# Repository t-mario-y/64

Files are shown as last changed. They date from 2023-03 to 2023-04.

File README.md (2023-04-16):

# 64

Splitted, Cherry MX switch, 64 keys, ortholinear mechanical keyboard.

MCU: [Waveshare RP2040-zero](https://www.waveshare.com/wiki/RP2040-Zero)  
Firmware: [KMK firmware](https://github.com/KMKfw/kmk_firmware)  

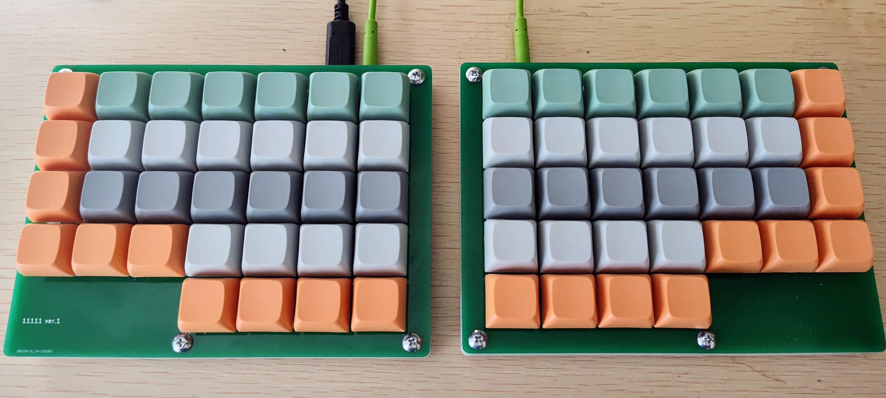
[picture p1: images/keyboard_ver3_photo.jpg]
keyboard photo. this is actually ver3 but top plates reuses ver1.


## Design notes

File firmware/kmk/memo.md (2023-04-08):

# Using KMK firmware

current working version:

- [Waveshare RP2040-zero](https://www.waveshare.com/wiki/RP2040-Zero)
- [CircuitPython 8.0.5](https://circuitpython.org/board/waveshare_rp2040_zero/)
- [KMK firmware b84cd0bdab5fce47534df7e6ccfbadb2e3288ba5](https://github.com/KMKfw/kmk_firmware/commit/b84cd0bdab5fce47534df7e6ccfbadb2e3288ba5)

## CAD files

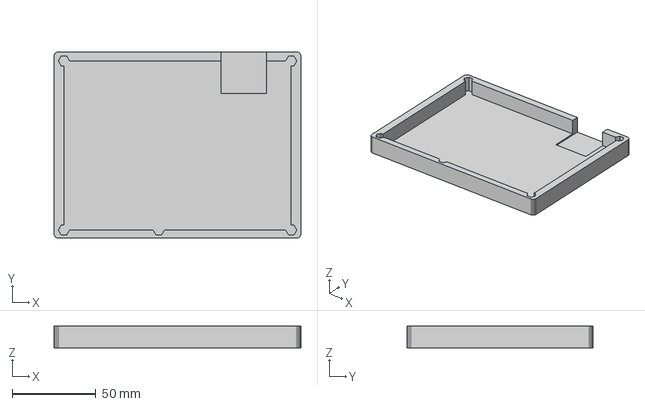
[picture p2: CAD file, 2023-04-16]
dist/ver3/models/left-case.step
147.4 x 111.1 x 13.0 mm

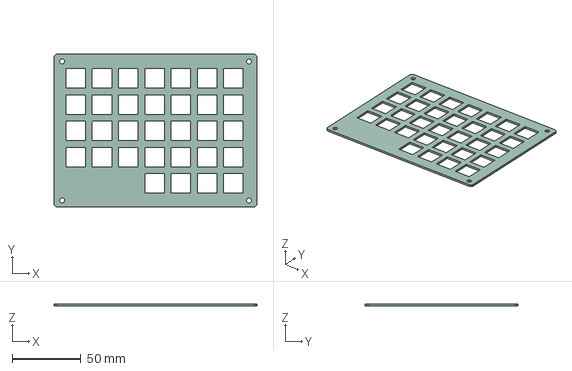
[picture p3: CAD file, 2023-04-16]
dist/ver3/models/top-plate.step
147.4 x 111.1 x 1.58 mm

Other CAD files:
dist/ver3/models/right-case.step
dist/ver3/models/left-case.stl
dist/ver3/models/right-case.stl
dist/ver3/models/top-plate.stl

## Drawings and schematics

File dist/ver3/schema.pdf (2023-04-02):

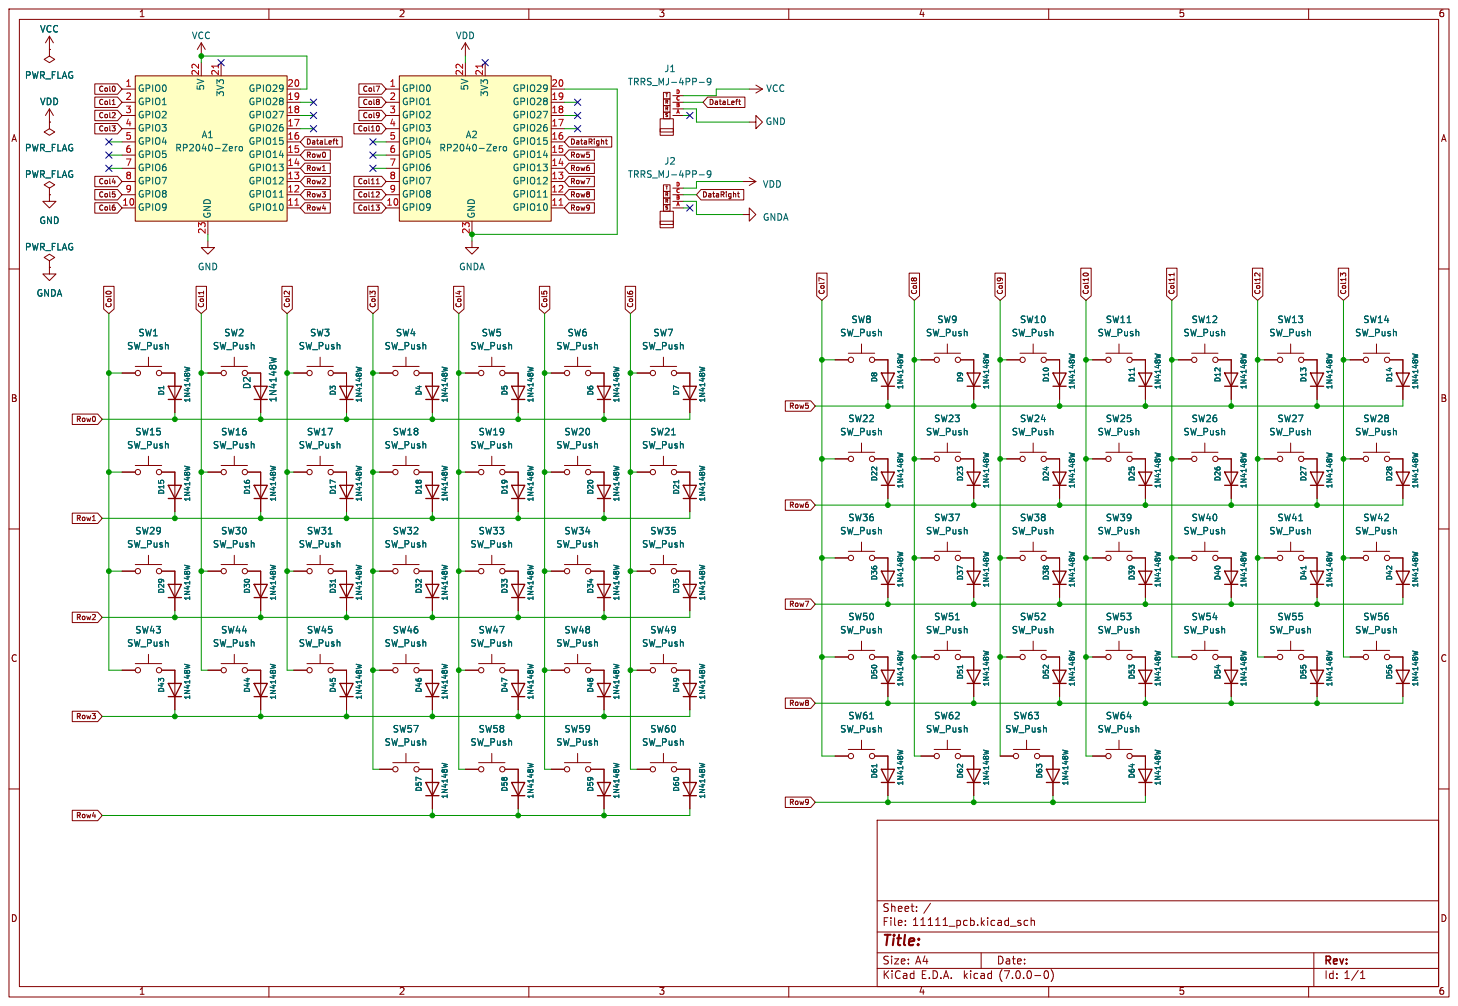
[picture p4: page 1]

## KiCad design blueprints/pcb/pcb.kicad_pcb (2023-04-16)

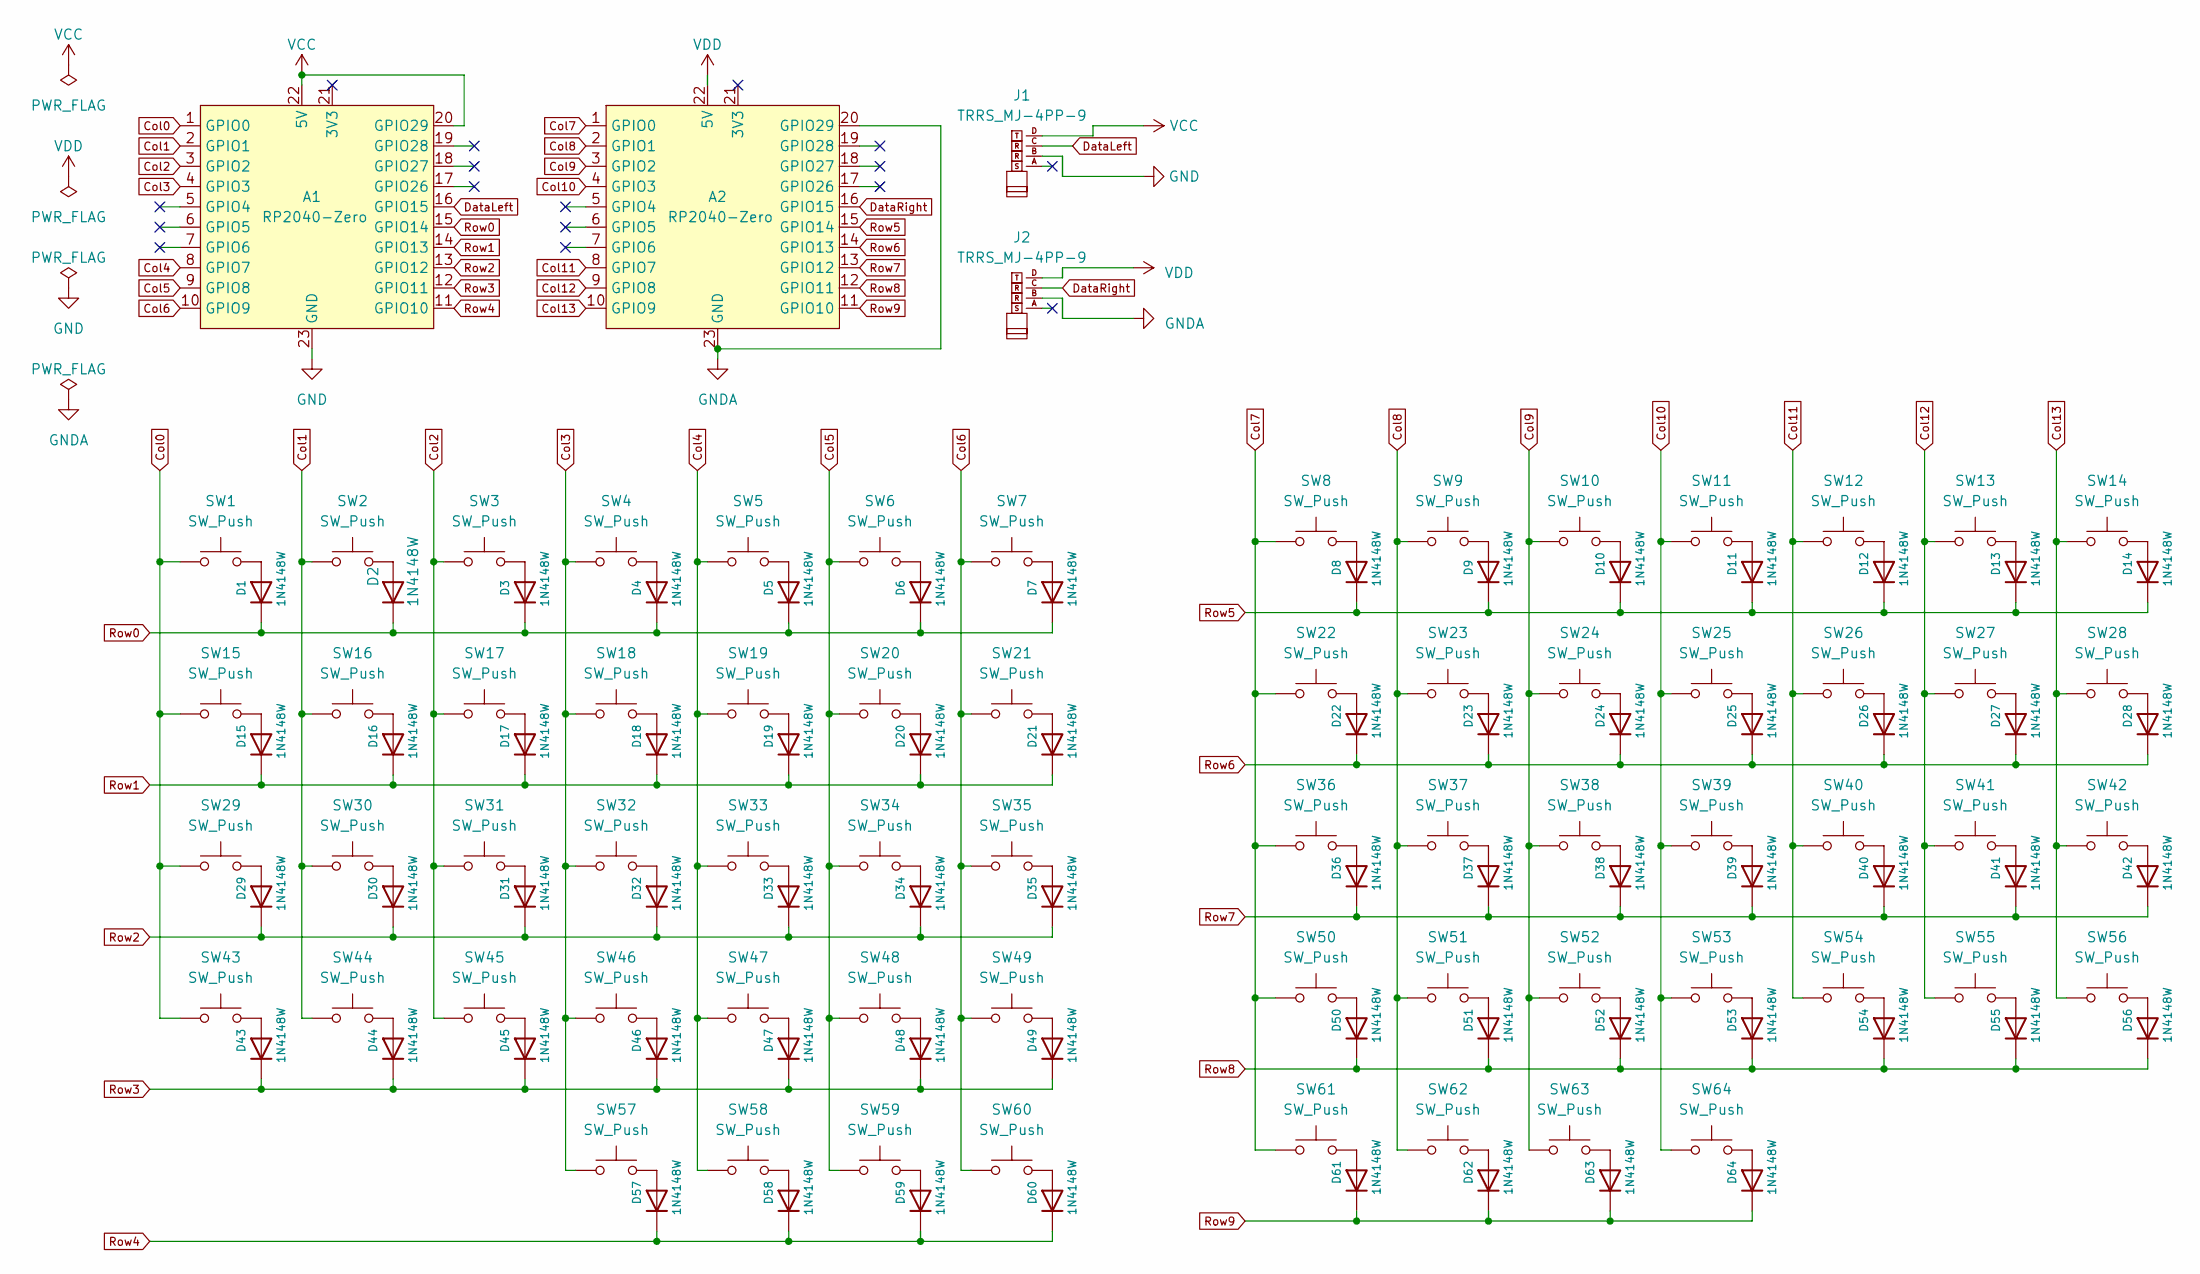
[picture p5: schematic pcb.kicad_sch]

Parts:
A1, A2: RP2040-Zero; RP2040-Zero_reversible
D1, D2, D3, D4, D5, D6, D7, D8, D9, D10, D11, D12, D13, D14, D15, D16, D17, D18, D19, D20, D21, D22, D23, D24, D25, D26, D27, D28, D29, D30, D31, D32, D33, D34, D35, D36, D37, D38, D39, D40, D41, D42, D43, D44, D45, D46, D47, D48, D49, D50, D51, D52, D53, D54, D55, D56, D57, D58, D59, D60, D61, D62, D63, D64: 1N4148W; Diode_SMD
J1, J2: TRRS_MJ-4PP-9
SW1, SW2, SW3, SW4, SW5, SW6, SW7, SW8, SW9, SW10, SW11, SW12, SW13, SW14, SW15, SW16, SW17, SW18, SW19, SW20, SW21, SW22, SW23, SW24, SW25, SW26, SW27, SW28, SW29, SW30, SW31, SW32, SW33, SW34, SW35, SW36, SW37, SW38, SW39, SW40, SW41, SW42, SW43, SW44, SW45, SW46, SW47, SW48, SW49, SW50, SW51, SW52, SW53, SW54, SW55, SW56, SW57, SW58, SW59, SW60, SW61, SW62, SW63, SW64: SW_Push; CherryMX_Solder_1u

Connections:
Col0: A1.1 (GPIO0), SW1.1, SW15.1, SW29.1, SW43.1
Col1: A1.2 (GPIO1), SW2.1, SW16.1, SW30.1, SW44.1
Col2: A1.3 (GPIO2), SW3.1, SW17.1, SW31.1, SW45.1
Col3: A1.4 (GPIO3), SW4.1, SW18.1, SW32.1, SW46.1, SW57.1
Col4: A1.8 (GPIO7), SW5.1, SW19.1, SW33.1, SW47.1, SW58.1
Col5: A1.9 (GPIO8), SW6.1, SW20.1, SW34.1, SW48.1, SW59.1
Col6: A1.10 (GPIO9), SW7.1, SW21.1, SW35.1, SW49.1, SW60.1
Col7: A2.1 (GPIO0), SW8.1, SW22.1, SW36.1, SW50.1, SW61.1
Col8: A2.2 (GPIO1), SW9.1, SW23.1, SW37.1, SW51.1, SW62.1
Col9: A2.3 (GPIO2), SW10.1, SW24.1, SW38.1, SW52.1, SW63.1
Col10: A2.4 (GPIO3), SW11.1, SW25.1, SW39.1, SW53.1, SW64.1
Col11: A2.8 (GPIO7), SW12.1, SW26.1, SW40.1, SW54.1
Col12: A2.9 (GPIO8), SW13.1, SW27.1, SW41.1, SW55.1
Col13: A2.10 (GPIO9), SW14.1, SW28.1, SW42.1, SW56.1
DataLeft: A1.16 (GPIO15), J1.C
DataRight: A2.16 (GPIO15), J2.C
GND: A1.23 (GND), J1.B
GNDA: A2.20 (GPIO29), A2.23 (GND), J2.B
unnamed: D1.2 (A), SW1.2
unnamed: D2.2 (A), SW2.2
unnamed: D3.2 (A), SW3.2
unnamed: D4.2 (A), SW4.2
unnamed: D5.2 (A), SW5.2
unnamed: D6.2 (A), SW6.2
unnamed: D7.2 (A), SW7.2
unnamed: D8.2 (A), SW8.2
unnamed: D9.2 (A), SW9.2
unnamed: D10.2 (A), SW10.2
unnamed: D11.2 (A), SW11.2
unnamed: D12.2 (A), SW12.2
unnamed: D13.2 (A), SW13.2
unnamed: D14.2 (A), SW14.2
unnamed: D15.2 (A), SW15.2
unnamed: D16.2 (A), SW16.2
unnamed: D17.2 (A), SW17.2
unnamed: D18.2 (A), SW18.2
unnamed: D19.2 (A), SW19.2
unnamed: D20.2 (A), SW20.2
unnamed: D21.2 (A), SW21.2
unnamed: D22.2 (A), SW22.2
unnamed: D23.2 (A), SW23.2
unnamed: D24.2 (A), SW24.2
unnamed: D25.2 (A), SW25.2
unnamed: D26.2 (A), SW26.2
unnamed: D27.2 (A), SW27.2
unnamed: D28.2 (A), SW28.2
unnamed: D29.2 (A), SW29.2
unnamed: D30.2 (A), SW30.2
unnamed: D31.2 (A), SW31.2
unnamed: D32.2 (A), SW32.2
unnamed: D33.2 (A), SW33.2
unnamed: D34.2 (A), SW34.2
unnamed: D35.2 (A), SW35.2
unnamed: D36.2 (A), SW36.2
unnamed: D37.2 (A), SW37.2
unnamed: D38.2 (A), SW38.2
unnamed: D39.2 (A), SW39.2
unnamed: D40.2 (A), SW40.2
unnamed: D41.2 (A), SW41.2
unnamed: D42.2 (A), SW42.2
unnamed: D43.2 (A), SW43.2
unnamed: D44.2 (A), SW44.2
unnamed: D45.2 (A), SW45.2
unnamed: D46.2 (A), SW46.2
unnamed: D47.2 (A), SW47.2
unnamed: D48.2 (A), SW48.2
unnamed: D49.2 (A), SW49.2
unnamed: D50.2 (A), SW50.2
unnamed: D51.2 (A), SW51.2
unnamed: D52.2 (A), SW52.2
unnamed: D53.2 (A), SW53.2
unnamed: D54.2 (A), SW54.2
unnamed: D55.2 (A), SW55.2
unnamed: D56.2 (A), SW56.2
unnamed: D57.2 (A), SW57.2
unnamed: D58.2 (A), SW58.2
unnamed: D59.2 (A), SW59.2
unnamed: D60.2 (A), SW60.2
unnamed: D61.2 (A), SW61.2
unnamed: D62.2 (A), SW62.2
unnamed: D63.2 (A), SW63.2
unnamed: D64.2 (A), SW64.2
Row0: A1.15 (GPIO14), D1.1 (K), D2.1 (K), D3.1 (K), D4.1 (K), D5.1 (K), D6.1 (K), D7.1 (K)
Row1: A1.14 (GPIO13), D15.1 (K), D16.1 (K), D17.1 (K), D18.1 (K), D19.1 (K), D20.1 (K), D21.1 (K)
Row2: A1.13 (GPIO12), D29.1 (K), D30.1 (K), D31.1 (K), D32.1 (K), D33.1 (K), D34.1 (K), D35.1 (K)
Row3: A1.12 (GPIO11), D43.1 (K), D44.1 (K), D45.1 (K), D46.1 (K), D47.1 (K), D48.1 (K), D49.1 (K)
Row4: A1.11 (GPIO10), D57.1 (K), D58.1 (K), D59.1 (K), D60.1 (K)
Row5: A2.15 (GPIO14), D8.1 (K), D9.1 (K), D10.1 (K), D11.1 (K), D12.1 (K), D13.1 (K), D14.1 (K)
Row6: A2.14 (GPIO13), D22.1 (K), D23.1 (K), D24.1 (K), D25.1 (K), D26.1 (K), D27.1 (K), D28.1 (K)
Row7: A2.13 (GPIO12), D36.1 (K), D37.1 (K), D38.1 (K), D39.1 (K), D40.1 (K), D41.1 (K), D42.1 (K)
Row8: A2.12 (GPIO11), D50.1 (K), D51.1 (K), D52.1 (K), D53.1 (K), D54.1 (K), D55.1 (K), D56.1 (K)
Row9: A2.11 (GPIO10), D61.1 (K), D62.1 (K), D63.1 (K), D64.1 (K)
VCC: A1.20 (GPIO29), A1.22 (5V), J1.D
VDD: A2.22 (5V), J2.D

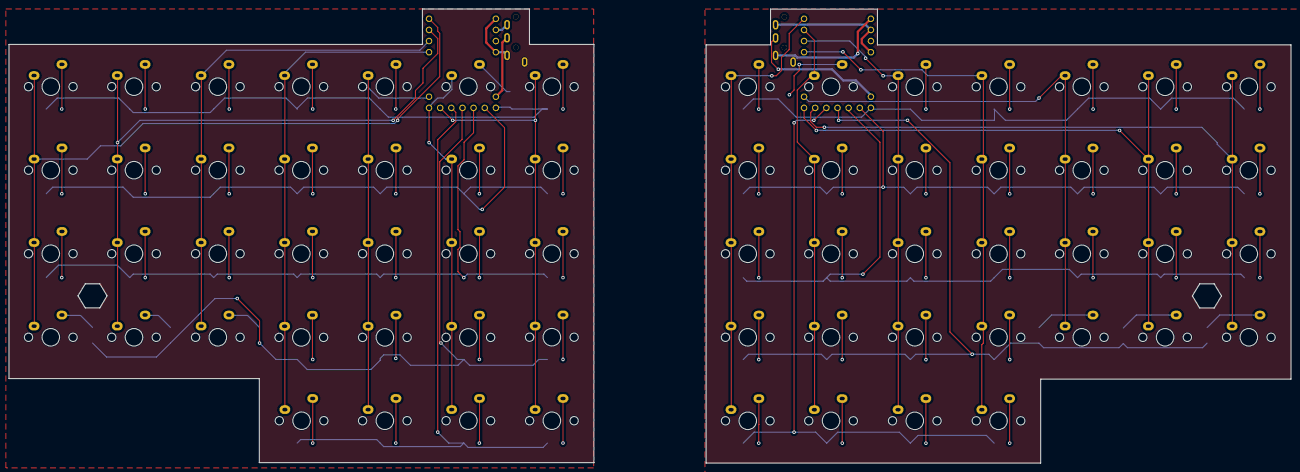
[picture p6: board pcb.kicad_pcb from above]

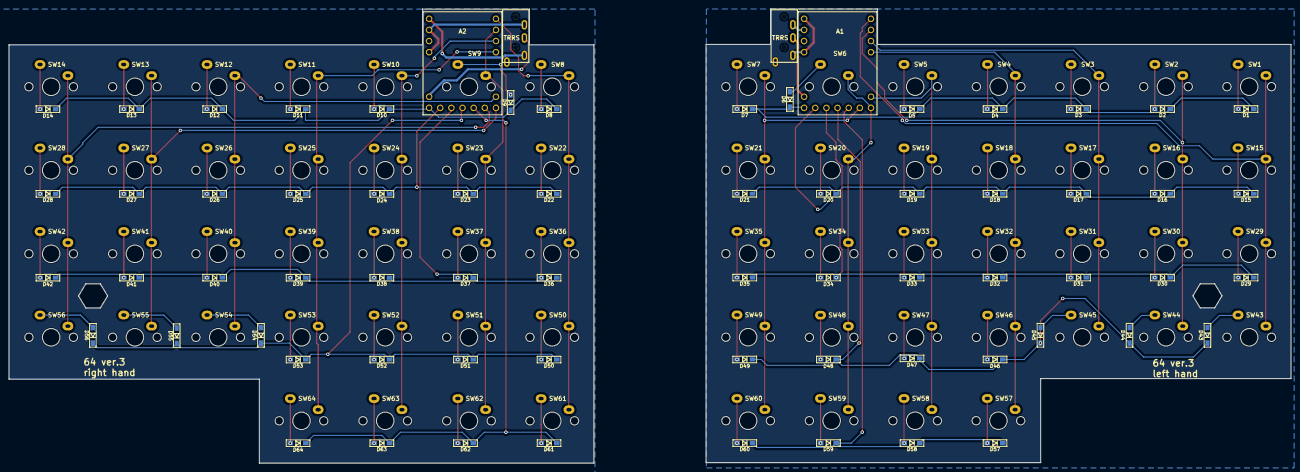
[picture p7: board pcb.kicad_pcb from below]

Board: 2 copper layers, 292.4 x 103.6 mm, 132 parts (2 on the bottom side), 94 nets.

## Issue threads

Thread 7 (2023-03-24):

ver.2で発注した3Dケースと右手基板が干渉していた

t-mario-y, 2023-03-24:
PCBと3Dケース両方を削ることで解消した。次回発注時に以下を実施する。

- 右手の3DケースのTRRSジャック穴の右側に1mmのクリアランスを設ける
- 基板側でTRRSジャックのシルクプリント外側を完全に削る

ただし、現時点でも組み上がるので試作版を完成させてから再発注でも良いかもしれない

t-mario-y, 2023-04-09:
ジャック用穴の横幅は問題なかった。
ただし、今度はピンヘッダの縦幅分の干渉が厳しい。別issueにて。

Closed 2023-04-09.

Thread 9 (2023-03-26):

右手（secondary）にファームウェアを書き込むのが大変なので頻繁にキーマップを変更しづらい

t-mario-y, 2023-03-26:
USBジャックの穴を右手側に出していないため、堅牢なケースとは両立しづらい。
- 基板のリセットスイッチが不要な方法でビルドする
- キーマップ変更を試行錯誤する時にはサンドイッチ構造を用いる

t-mario-y, 2023-04-09:
そもそもUSBジャックを右手ケースにも開けた。また、KMK firmwareであればUSBマスストレージ認識を切り替えやすいので、あまり困らなくなった。

Closed 2023-04-09.

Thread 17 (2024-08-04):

USBストレージ認識の制御を容易にしたい

t-mario-y, 2024-08-04:
[CircuitPythonで作ったデバイスの普段使いに邪魔なUSBドライブを無効化する（ただし7.0.0から）](https://akkiesoft.hatenablog.jp/entry/20210816/1629108171) の通り。

CircuitPython を使用する以上はハードウェア設計時に考慮が必要なポイントになる。

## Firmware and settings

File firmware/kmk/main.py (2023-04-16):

from kb import KMKKeyboard
from kmk.keys import KC
from kmk.modules.holdtap import HoldTap
from kmk.modules.layers import Layers
from kmk.modules.split import Split, SplitType

print("Starting 64 keyboard.")

keyboard = KMKKeyboard()
keyboard.tap_time = 150

layers = Layers()
hold_tap = HoldTap()
split = Split(
    split_type=SplitType.UART, split_flip=True, data_pin=keyboard.data_pin, use_pio=True
)
keyboard.modules = [layers, hold_tap, split]

LOWER_EISU = KC.HT(KC.LANG2, KC.MO(1))
RAISE_KANA = KC.HT(KC.LANG1, KC.MO(2))

# fmt: off
keyboard.keymap = [
    [
        KC.ESC,   KC.N1,    KC.N2,    KC.N3,    KC.N4,    KC.N5,     KC.MINS,  KC.EQL,   KC.N6,     KC.N7,    KC.N8,    KC.N9,    KC.N0,    KC.GRV,
        KC.TAB,   KC.Q,     KC.W,     KC.E,     KC.R,     KC.T,      KC.LBRC,  KC.RBRC,  KC.Y,      KC.U,     KC.I,     KC.O,     KC.P,     KC.BSPC,
        KC.LCTL,  KC.A,     KC.S,     KC.D,     KC.F,     KC.G,      KC.BSLS,  KC.SLSH,  KC.H,      KC.J,     KC.K,     KC.L,     KC.SCLN,  KC.QUOT,
        KC.LSFT,  KC.Z,     KC.X,     KC.C,     KC.V,     KC.B,      KC.PGUP,  KC.PGDN,  KC.N,      KC.M,     KC.COMM,  KC.DOT,   KC.HOME,  KC.RSFT,
                                      KC.LALT,  KC.LGUI,  LOWER_EISU,KC.SPC,   KC.ENT,   RAISE_KANA,KC.RALT,  KC.END,
    ],
    [
        KC.ESC,   KC.F1,    KC.F2,    KC.F3,    KC.F4,    KC.F5,     KC.F11,   KC.F12,   KC.F6,     KC.F7,    KC.F8,    KC.F9,    KC.F10,   KC.GRV,
        KC.TAB,   KC.Q,     KC.W,     KC.E,     KC.R,     KC.T,      KC.LBRC,  KC.RBRC,  KC.Y,      KC.U,     KC.I,     KC.O,     KC.P,     KC.BSPC,
        KC.LCTL,  KC.A,     KC.S,     KC.D,     KC.F,     KC.G,      KC.BSLS,  KC.SLSH,  KC.LEFT,   KC.DOWN,  KC.UP,    KC.RIGHT, KC.SCLN,  KC.QUOT,
        KC.LSFT,  KC.Z,     KC.X,     KC.C,     KC.V,     KC.B,      KC.PGUP,  KC.PGDN,  KC.N,      KC.M,     KC.COMM,  KC.DOT,   KC.HOME,  KC.RSFT,
                                      KC.LALT,  KC.LGUI,  LOWER_EISU,KC.SPC,   KC.ENT,   RAISE_KANA,KC.RALT,  KC.END,
    ],
    [
        KC.ESC,   KC.F1,    KC.F2,    KC.F3,    KC.F4,    KC.F5,     KC.F11,   KC.F12,   KC.F6,     KC.F7,    KC.F8,    KC.F9,    KC.F10,   KC.GRV,
        KC.TAB,   KC.Q,     KC.W,     KC.E,     KC.R,     KC.T,      KC.LBRC,  KC.RBRC,  KC.Y,      KC.U,     KC.I,     KC.O,     KC.P,     KC.DEL,
        KC.LCTL,  KC.A,     KC.S,     KC.D,     KC.F,     KC.G,      KC.BSLS,  KC.SLSH,  KC.LEFT,   KC.DOWN,  KC.UP,    KC.RIGHT, KC.SCLN,  KC.QUOT,
        KC.LSFT,  KC.Z,     KC.X,     KC.C,     KC.V,     KC.B,      KC.PGUP,  KC.PGDN,  KC.N,      KC.M,     KC.COMM,  KC.DOT,   KC.HOME,  KC.RSFT,
                                      KC.LALT,  KC.LGUI,  LOWER_EISU,KC.SPC,   KC.ENT,   RAISE_KANA,KC.RALT,  KC.END,
    ]
]

# fmt: on
if __name__ == "__main__":
    keyboard.go()

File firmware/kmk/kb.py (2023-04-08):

import board

from kmk.kmk_keyboard import KMKKeyboard as _KMKKeyboard
from kmk.scanners import DiodeOrientation


class KMKKeyboard(_KMKKeyboard):
    # fmt: off
    row_pins = (board.GP14, board.GP13, board.GP12, board.GP11, board.GP10)
    col_pins = (board.GP0, board.GP1, board.GP2, board.GP3, board.GP7, board.GP8, board.GP9)
    # fmt: on
    data_pin = board.GP15
    diode_orientation = DiodeOrientation.COL2ROW
    # fmt: off
    coord_mapping = [
     0,  1,  2,  3,  4,  5,  6,  35, 36, 37, 38, 39, 40, 41,
     7,  8,  9, 10, 11, 12, 13,  42, 43, 44, 45, 46, 47, 48,
    14, 15, 16, 17, 18, 19, 20,  49, 50, 51, 52, 53, 54, 55,
    21, 22, 23, 24, 25, 26, 27,  56, 57, 58, 59, 60, 61, 62,
                31, 32, 33, 34,  63, 64, 65, 66
    ]
    # fmt: on

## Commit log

2023-02-27 add PCB Schematic
    [11111.kicad_pcb, 11111.kicad_sch]
2023-02-27 update schematic
    [11111.kicad_sch]
2023-02-27 fix VCC pin
    [11111.kicad_sch]
2023-02-27 add right schematic
    [11111.kicad_sch]
2023-02-28 update symbol and footprint library
2023-02-28 use imported symbol for MJ-4PP-9
    [11111.kicad_sch]
2023-02-28 import schematic in success
    [11111.kicad_pcb]
2023-02-28 fix schematic
    [11111.kicad_sch]
2023-02-28 edit PCB
    [11111.kicad_pcb]
2023-03-01 add Raspberry pi pico library
    [11111.kicad_pcb, 11111.kicad_sch]
2023-03-01 update KiCad symbol/footprint library
2023-03-01 update PCB, use Raspberry Pi Pico
    [11111.kicad_pcb, 11111.kicad_sch]
2023-03-02 チェックエラーが0件になるまでPCB配線した
    [11111.kicad_pcb]
2023-03-02 reduce silkscreen warnings
    [11111.kicad_pcb]
2023-03-02 オモテウラを間違えていたので修正
    [11111.kicad_pcb, 11111.kicad_sch]
2023-03-05 update PCB
    [11111.kicad_pcb, 11111.kicad_sch]
2023-03-05 add 2 switches
    [11111.kicad_pcb, 11111.kicad_sch]
2023-03-05 fix PCB Edge.Cuts
    [11111.kicad_pcb]
2023-03-05 create top and bottom plates
    [11111.kicad_pcb, 11111.kicad_sch]
2023-03-05 GNDを塗りつぶし
    [11111.kicad_pcb, 11111.kicad_sch]
2023-03-05 print version 0.1
    [11111.kicad_pcb]
2023-03-05 plot gerber files for v0.1
    [11111-B_Cu.gbr, 11111-B_Mask.gbr, 11111-B_Silkscreen.gbr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]
2023-03-05 rename project to divide PCB and plates
    [11111_pcb.kicad_pcb, 11111_pcb.kicad_sch, 11111_plates.kicad_pcb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]
2023-03-05 export gerber for v0.1 again
    [11111_pcb-B_Cu.gbr, 11111_pcb-B_Mask.gbr, 11111_pcb-B_Silkscreen.gbr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]
2023-03-05 modify plate
    [11111_plates.kicad_pcb]
2023-03-05 divide gerber files for 4 kinds plates
    [11111_pcb-B_Cu.gbr, 11111_pcb-B_Mask.gbr, 11111_pcb-B_Silkscreen.gbr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]
2023-03-05 Raspberry Pi Picoの箇所に穴をあける
    [11111_pcb.kicad_pcb]
2023-03-05 modify PCB and plates
    [11111_pcb.kicad_pcb, 11111_plates.kicad_pcb]
2023-03-05 publish v0.1
    [11111_pcb-B_Cu.gbr, 11111_pcb-B_Mask.gbr, 11111_pcb-B_Silkscreen.gbr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]
2023-03-06 update v0.1 gerber
    [11111_pcb-B_Cu.gbr, 11111_pcb-B_Mask.gbr, 11111_pcb-B_Silkscreen.gbr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]
2023-03-11 export step file
    [11111_plates.step]
2023-03-12 add User.Drawings to plate
    [11111_plates.kicad_pcb]
2023-03-12 narrow left PCB
    [11111_pcb.kicad_pcb]
2023-03-12 narrow right PCB
    [11111_pcb.kicad_pcb]
2023-03-13 print 'ver.2' on plates
    [11111_plates.kicad_pcb]
2023-03-14 modify PCB
    [11111_pcb.kicad_pcb]
2023-03-14 export STEP
    [11111_plates.step]
2023-03-15 rename and modify v0.1 files
    [11111_pcb-B_Cu.gbr, 11111_pcb-B_Mask.gbr, 11111_pcb-B_Silkscreen.gbr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]
2023-03-15 add step files for ver2
    [11111_left-case.step, 11111_left-top-plate.step, 11111_right-case.step]
2023-03-16 print to PDF
2023-03-19 export ver.2 gerber files
    [11111_pcb-B_Cu.gbr, 11111_pcb-B_Mask.gbr, 11111_pcb-B_Silkscreen.gbr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]
2023-04-02 add gerbers
    [11111_pcb-B_Cu.gbr, 11111_pcb-B_Mask.gbr, 11111_pcb-B_Silkscreen.gbr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]
2023-04-02 export models
    [11111_left-case.step, 11111_left-case.stl, 11111_right-case.step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]
2023-04-08 edit KiCad libraries
    [11111_pcb.kicad_pcb, 11111_pcb.kicad_sch]
2023-04-15 export top plate step file from KiCad
    [11111_plates.kicad_pcb, 11111_top-plate.step]
2023-04-15 export step & stl files
    [11111_top-plate.step, 11111_top-plate.stl]
2023-04-15 export gerber files
    [11111_plates-B_Cu.gbr, 11111_plates-B_Mask.gbr, 11111_plates-B_Silkscreen.gbr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]
2023-04-15 rename dir
    [11111_pcb-B_Cu.gbr, 11111_pcb-B_Mask.gbr, 11111_pcb-B_Silkscreen.gbr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]
2023-04-15 left/right case step & stl files
    [11111_left-case.step, 11111_left-case.stl, 11111_right-case.step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]
2023-04-16 remove old versions build
    [11111_left-case.step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]
2023-04-16 update silk print text
    [11111_plates.kicad_pcb]
2023-04-16 remove unused referring
    [11111_plates.kicad_pcb]
2023-04-16 rename plates project
    [plates.kicad_pcb, plates.kicad_sch]
2023-04-16 export top plate step file
    [top-plate.step]
2023-04-16 rename PCB kicad project
    [pcb.kicad_pcb, pcb.kicad_sch]
2023-04-16 fix silk print
    [pcb.kicad_pcb]
2023-04-16 export PCB step file
2023-04-16 plot gerber files
    [11111_plates-F_Silkscreen.gbr, pcb-B_Cu.gbr, pcb-B_Mask.gbr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]
2023-04-16 fix 11111 to 64
    [main.py]
2023-04-16 rename and export models again
    [left-case.step, left-case.stl, right-case.step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]
